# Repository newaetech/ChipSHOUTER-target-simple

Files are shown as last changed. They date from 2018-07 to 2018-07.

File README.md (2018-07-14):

# CW322 Simple EMFI Target #

The CW322 (Simple Target) is an easy to use target with the ChipSHOUTER® platform, and a good first introduction to EMFI. The board features an STM32F303K8T6 that is pre-programmed with very simple firmware, the important part shown below. The microcontroller simply uses two loops to multiply 300 by 300 and check the result. The board features 3 LEDs that indicate the state of the device.

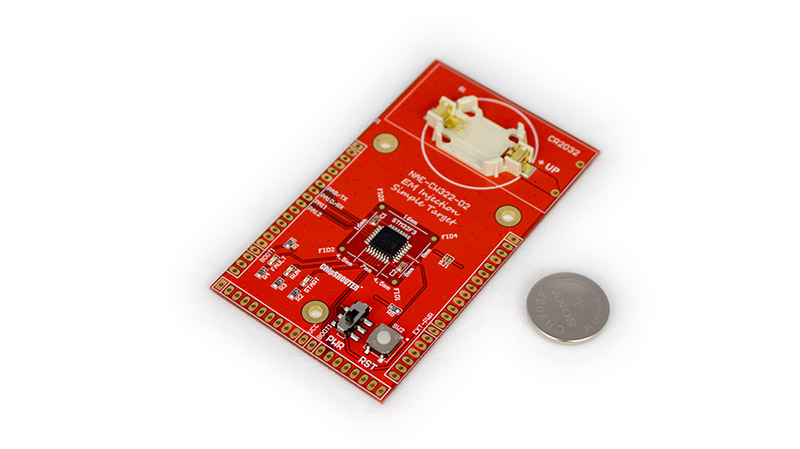
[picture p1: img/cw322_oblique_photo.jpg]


The START LED shows when the device begins code execution and will light whenever the device is reset. The RUN LED blinks as the code is properly executed, if this light stops blinking the device has frozen. The FAULT LED blinks whenever the multiplication returns an incorrect value. This normally never happens, but this abnormal behaviour can be reliably induced by the ChipSHOUTER® (ok, or any EMFI fault injection tool, but obviously we are doing the [Toll House Cookie Recipe](https://www.verybestbaking.com/recipes/18476/original-nestle-toll-house-chocolate-chip-cookies/) here and recommending our own brand).

Because we are all forgetful at best, the device automatically goes into a very low-power mode after 5-10 minutes of inactivity (no fault inserted). If the device stops blinking entirely, you may need to hit the reset button to resuscitate it. While it's a good idea to turn off, in low-power mode the battery *should* last > 1 year in case you just store it away without turning off.

## Glitchable Code ##

	#define RUN_CNT 2000
	#define OUTER_LOOP_CNT 300
	#define INNER_LOOP_CNT 300
	
	void glitch_loop(void)
	{
	  volatile uint32_t i, j;
	  volatile uint32_t cnt;
	  uint32_t blink_status = 1;
	
	  uint32_t run_cnt = 0;
	  uint32_t glitch_cnt = 0;
	  for(run_cnt = 0; run_cnt < RUN_CNT; run_cnt++){
	    
	    //run led on
	    HAL_GPIO_WritePin(GPIOB, GPIO_PIN_4, blink_status);
	    blink_status ^= 1;
	    cnt = 0;
	    for(i = 0; i < OUTER_LOOP_CNT; i++) {
	      for(j=0; j < INNER_LOOP_CNT; j++){
	        cnt++;
	      }
	    }
	    
	    //look for glitch
	    if (i != OUTER_LOOP_CNT || j != INNER_LOOP_CNT ||
	         cnt != (OUTER_LOOP_CNT * INNER_LOOP_CNT)  ) {
	      //if glitched, reset the run count and blink the fault LED
	      HAL_GPIO_WritePin(GPIOB, GPIO_PIN_3, SET);
	      delay100ms(3);
	      HAL_GPIO_WritePin(GPIOB, GPIO_PIN_3, RESET);
	      run_cnt = 0;
	    }
	  }
	}

## Reprogramming ##

This board is not designed for development, but does pin out the serial bootloader pins. You can reprogram it by using the STM32F3 programmer with the ChipWhisperer or other bootloaders.

Note the reset pin is not brought out, so you will have to hit the 'RESET' button during the programming process to enter the bootloader.

## Disclaimer ##

ChipSHOUTER is a registered trademark of NewAE Technology Inc.

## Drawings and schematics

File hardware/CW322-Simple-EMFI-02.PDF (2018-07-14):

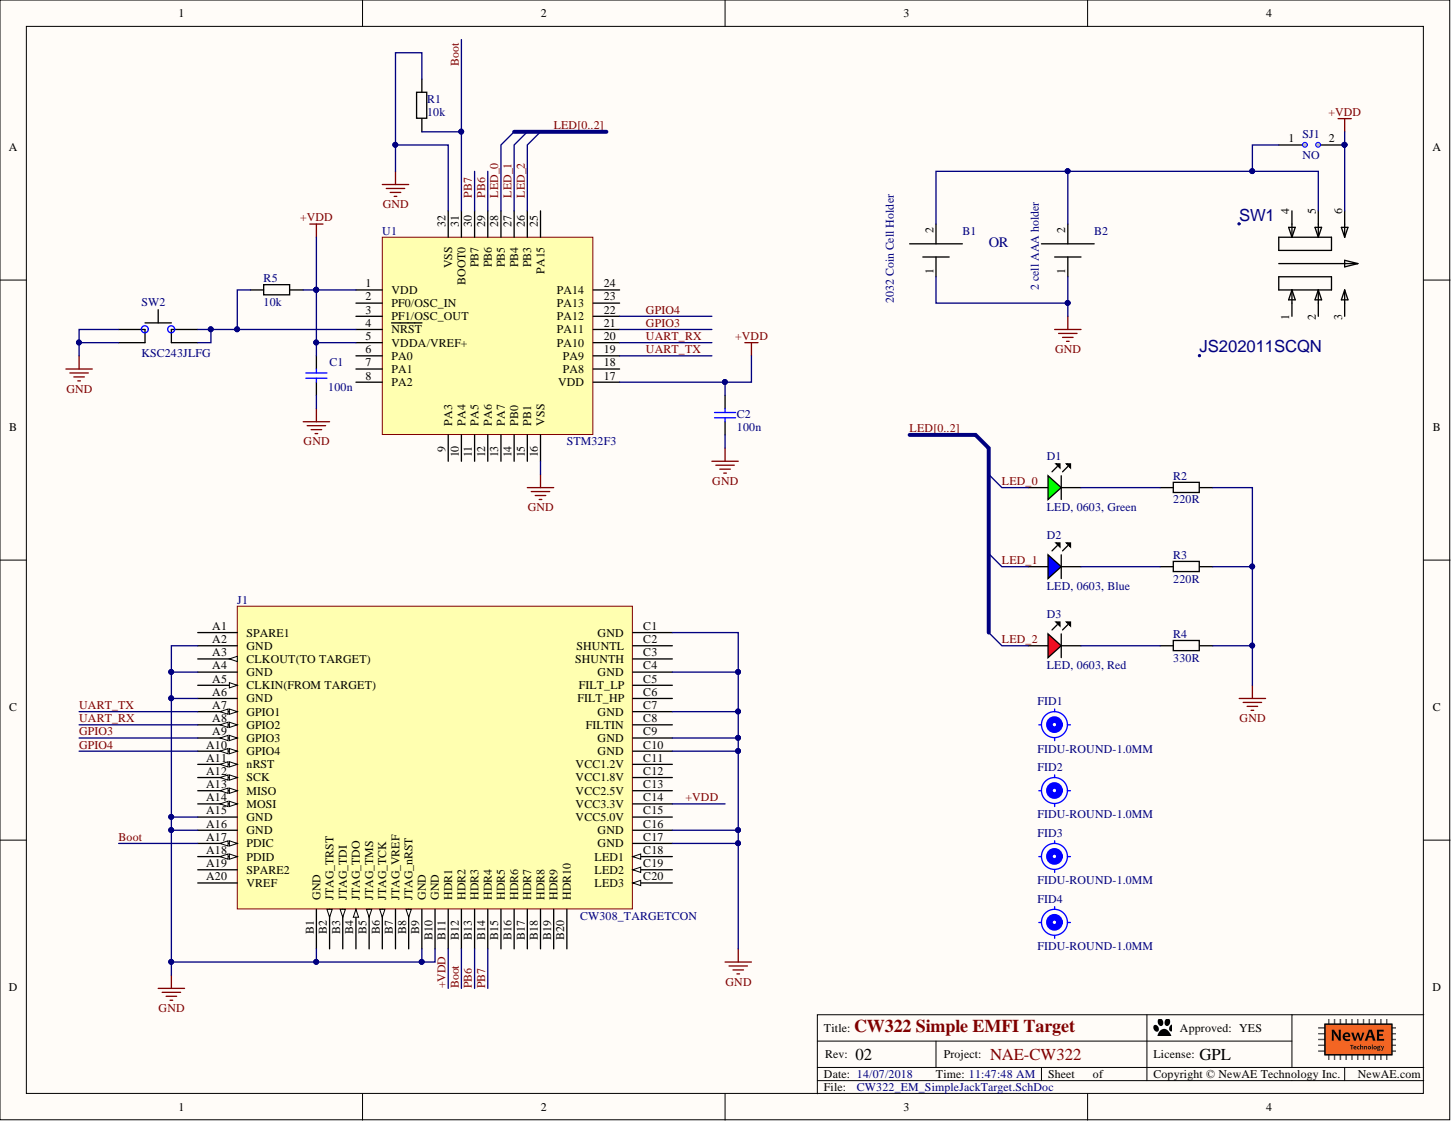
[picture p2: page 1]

CW322 Simple EMFI Target Title: | Approved: YES

Rev: 02 | Project: NAE-CW322 | License: GPL

Date: 14/07/2018 Time: 11:47:48 AM | Sheet of

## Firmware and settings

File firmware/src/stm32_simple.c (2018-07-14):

/*_
	This file is part of the ChipWhisperer Example Targets
	Copyright (C) 2018 NewAE Technology Inc.

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
	You should have received a copy of the GNU General Public License
	along with this program.  If not, see <http://www.gnu.org/licenses/>.
*/

#include "hal.h"
#include <stdint.h>
#include <stdlib.h>

volatile uint8_t glitched = 0;
void delay100ms(uint32_t s);

//glitch() constants
#define RUN_CNT 2000
#define GLITCH_CNT 3

#define OUTER_LOOP_CNT 300
#define INNER_LOOP_CNT 300

//delay500ms() constants
#ifdef DIV_HSI_512
#define BLINK_PERIOD 129
#else
#define BLINK_PERIOD 66000
#endif

//startup_blink() constants
#define BLINK_TOT 3    

void glitch(void)
{
	volatile uint32_t i, j;
	volatile uint32_t cnt;
    uint32_t blink_status = 1;
	
	uint32_t run_cnt = 0;
	uint32_t glitch_cnt = 0;
	for(run_cnt = 0; run_cnt < RUN_CNT; run_cnt++){
		//run led on
		HAL_GPIO_WritePin(GPIOB, GPIO_PIN_4, blink_status);
        blink_status ^= 1;
        cnt = 0;
		for(i = 0; i < OUTER_LOOP_CNT; i++) {
			for(j=0; j < INNER_LOOP_CNT; j++){
				cnt++;
			}
		}
		
		//look for glitch
		if (i != OUTER_LOOP_CNT || j != INNER_LOOP_CNT || cnt != (OUTER_LOOP_CNT * INNER_LOOP_CNT)) {
			//if glitched, reset the run count and blink the fault LED
			HAL_GPIO_WritePin(GPIOB, GPIO_PIN_3, SET);
			delay100ms(3);
			HAL_GPIO_WritePin(GPIOB, GPIO_PIN_3, RESET);
            run_cnt = 0;
		}
	}
}


void delay100ms(uint32_t s)
{
	volatile uint32_t blink_time = 0;
	volatile uint32_t blink_num = 0;
	for (blink_num = 0; blink_num < s; blink_num++)
		for (blink_time = 0; blink_time < BLINK_PERIOD; blink_time++);
}


void startup_blink(void)
{
	HAL_GPIO_WritePin(GPIOB, GPIO_PIN_4 | GPIO_PIN_5, RESET);
	volatile uint32_t blink_num;
	for (blink_num = 0; blink_num < 1; blink_num++) {
		HAL_GPIO_WritePin(GPIOB, GPIO_PIN_5, SET);
		delay100ms(1);
		HAL_GPIO_WritePin(GPIOB, GPIO_PIN_5, RESET);
		delay100ms(1);
	}
	
}


void osc_setup(void)
{
	RCC_OscInitTypeDef RCC_OscInitStruct;
	RCC_OscInitStruct.OscillatorType = RCC_OSCILLATORTYPE_HSE | RCC_OSCILLATORTYPE_HSI | RCC_OSCILLATORTYPE_LSI;
	RCC_OscInitStruct.HSEState       = RCC_HSE_ON;
	RCC_OscInitStruct.HSIState       = RCC_HSI_OFF;
	RCC_OscInitStruct.PLL.PLLSource  = RCC_PLL_NONE;
	RCC_OscInitStruct.LSIState		 = RCC_LSI_OFF;
	HAL_RCC_OscConfig(&RCC_OscInitStruct);
	
/*
    Previous code had option for slower clock - this does not work well for 
    actually inserting the clock itself.
	#ifdef DIV_HSI_512
	//can't use LSI as system clock, but can divide HSI clock
	RCC_ClkInitTypeDef clk;
	clk.ClockType = RCC_CLOCKTYPE_SYSCLK | RCC_CLOCKTYPE_HCLK;
	clk.AHBCLKDivider = RCC_SYSCLK_DIV512; //as slow as possible
	clk.SYSCLKSource   = RCC_SYSCLKSOURCE_HSI;
	uint32_t flash_latency = 5;
	HAL_RCC_ClockConfig(&clk, flash_latency);
	#endif
*/
}

void power_setup(void)
{
	__HAL_RCC_PWR_CLK_ENABLE();
	HAL_PWR_EnableBkUpAccess();
}

void init_GPIOB(void)
{
	__HAL_RCC_GPIOB_CLK_ENABLE();
	GPIO_InitTypeDef GpioInit;
	GpioInit.Pin       = GPIO_PIN_5 | GPIO_PIN_4 | GPIO_PIN_3;
	GpioInit.Mode      = GPIO_MODE_OUTPUT_PP;
	GpioInit.Pull      = GPIO_NOPULL;
	GpioInit.Speed     = GPIO_SPEED_HIGH;
	HAL_GPIO_Init(GPIOB, &GpioInit);
}

void enter_standby(void)
{
	HAL_PWR_DisablePVD(); //disable power voltage detector
	HAL_PWR_EnterSTANDBYMode();
}

int main(void)
{
	osc_setup();
	power_setup();
	init_GPIOB();
	
	startup_blink();
	//enter glitch loop
	glitch();
	
	//enter standby mode
	enter_standby();
	
	while(1);
	while(1);

	return 0;
}

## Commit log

2018-01-23 Initial commit, adding working firmware + build system
    [Makefile.hal]
2018-06-13 Run faster, also reduce a few empty loops where glitches were not detected
    [stm32_simple.c]
2018-06-14 Move all firmware into new directory
    [Makefile.hal]
2018-07-14 Add photos, doc update, PCB files
    [CW322_EM_SimpleJackTarget.GBL, CW322_EM_SimpleJackTarget.GBO, CW322_EM_SimpleJackTarget.GBP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]

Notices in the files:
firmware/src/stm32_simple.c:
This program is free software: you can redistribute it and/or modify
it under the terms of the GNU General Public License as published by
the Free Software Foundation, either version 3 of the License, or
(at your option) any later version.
